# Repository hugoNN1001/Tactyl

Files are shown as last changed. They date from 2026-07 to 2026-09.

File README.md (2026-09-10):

# Tactyl

Tactyl is a gesture-based typing interface that lets you type anywhere without a keyboard. It converts finger taps into digital characters, avoiding the fixed workspace and repetitive wrist/hand positioning that conventional keyboards require.

## Photos
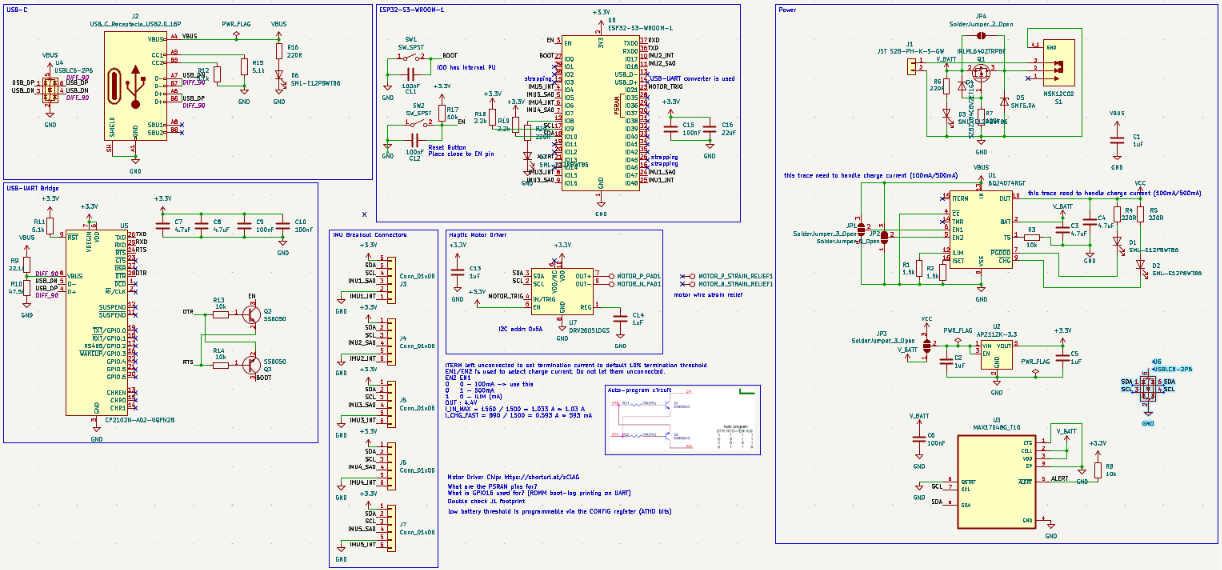
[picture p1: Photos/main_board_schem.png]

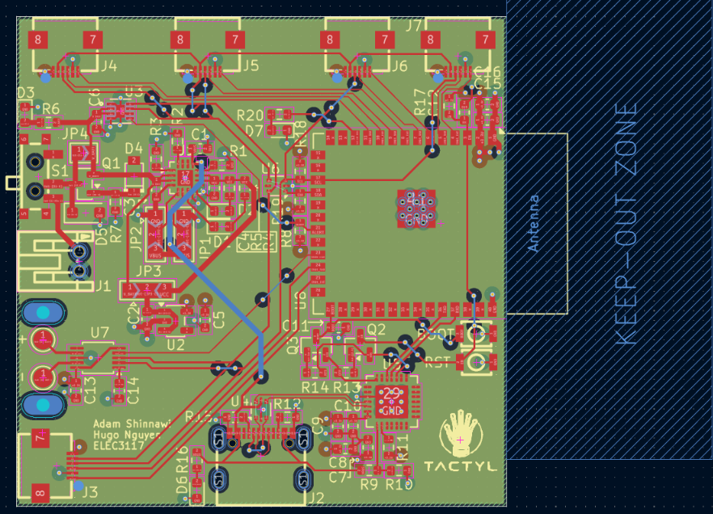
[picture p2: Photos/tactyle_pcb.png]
 
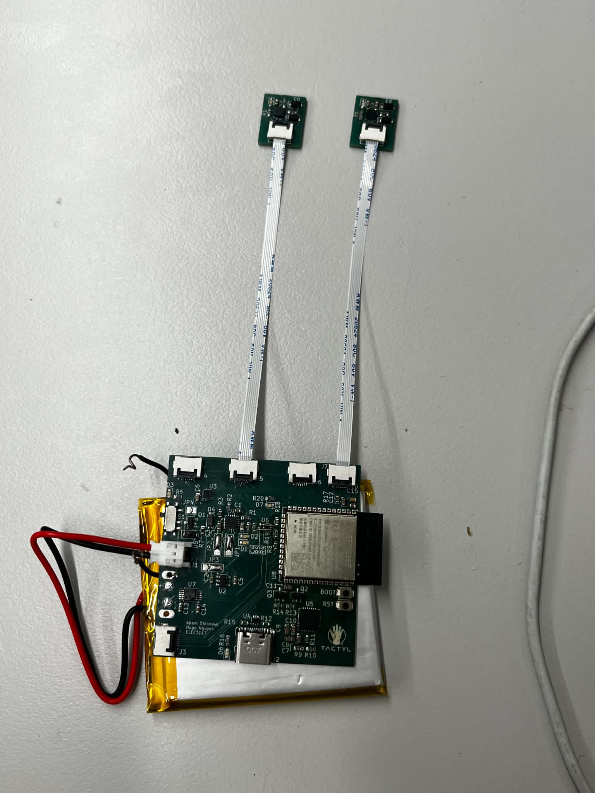
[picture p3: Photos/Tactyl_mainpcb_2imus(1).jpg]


## How It Works

Tactyl uses a **five-bit chorded input** scheme: each of the five fingers acts as one bit. Tapping different finger combinations produces unique 5-bit codes, which are mapped in software to characters and commands. This gives 32 possible combinations enough to cover the full alphabet.

Finger movement is tracked by five IMUs (one per finger) embedded in the glove, allowing the system to distinguish intentional taps from general hand motion. Sensor data is processed by an ESP32-based embedded controller and transmitted wirelessly to a host computer. A haptic feedback system provides confirmation of typed characters and connection status.

## System Architecture

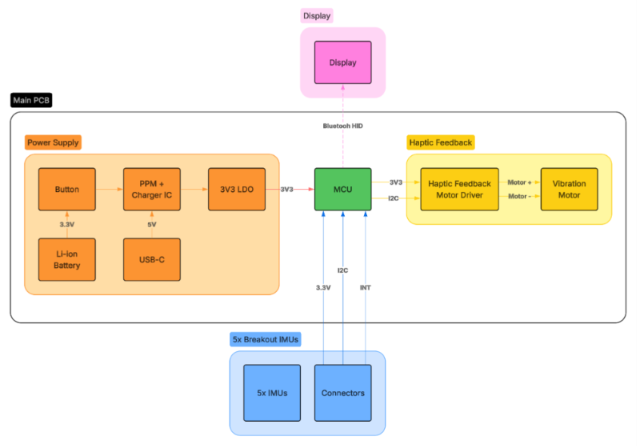
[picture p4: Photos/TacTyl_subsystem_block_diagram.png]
Tactyl subsystem block diagram


**Sensing layer.** Five **IMUs**, one per finger, each measuring acceleration to detect individual finger taps independently. Since they all share the same I²C address, a **TCA9548A I²C multiplexer** separates them into independent channels to faciliate communication.

**Power.** A **BQ24074 linear charge management IC** handles Li-ion battery charging while supporting system load via its **power-path output**. Charge current (300mA/500 mA) is selectable via solder jumpers. **Reverse polarity protection** is implemented with a P-FET with a **G-S protection diode**. The 3.3 V rail is generated by a **AP2112 LDO**. A **MAX17048 fuel gauge** monitors voltage/SOC over I²C and asserts an ALERT interrupt for **low-battery detection**, feeding the firmware's haptic alert logic. Main power traces were sized appropriate to handle the expected load. 

**Programming.** A **CP2102 USB-UART bridge** converts USB differential signals to UART to program the ESP32. Differential traces are kept short and **sized to 90Ω impedance**. ESD protection diodes are placed as close to the USB-C connector as possible.

**Processing.** An **ESP32-S3 microcontroller** processes sensor inputs, runs tap detection, maintains the five-bit finger state register, performs chord recognition, and manages communication with the host device. Each completed chord is looked up in a table and converted into the corresponding character. An **auto-program circuit** is also implemented with a pair to MOSFETs to automatically trigger BOOT & RST when programming.

**Wireless communication.** The interpreted character is transmitted over **Bluetooth Low Energy (BLE)** from the ESP32-S3 to the host device. The antenna keep-out section is kept clear of any copper.

**Haptic feedback.** A vibration motor, driven by a **DRV2605L haptic driver**, gives the user tactile confirmation of events such as BLE connection/disconnection state and low power. An **ERM coin vibration motor** is mounted through **strain-relief holes** on the main PCB. For the next version, a better decoupling capacitor should be added to prevent the ESP from resetting during strong motor vibrations.

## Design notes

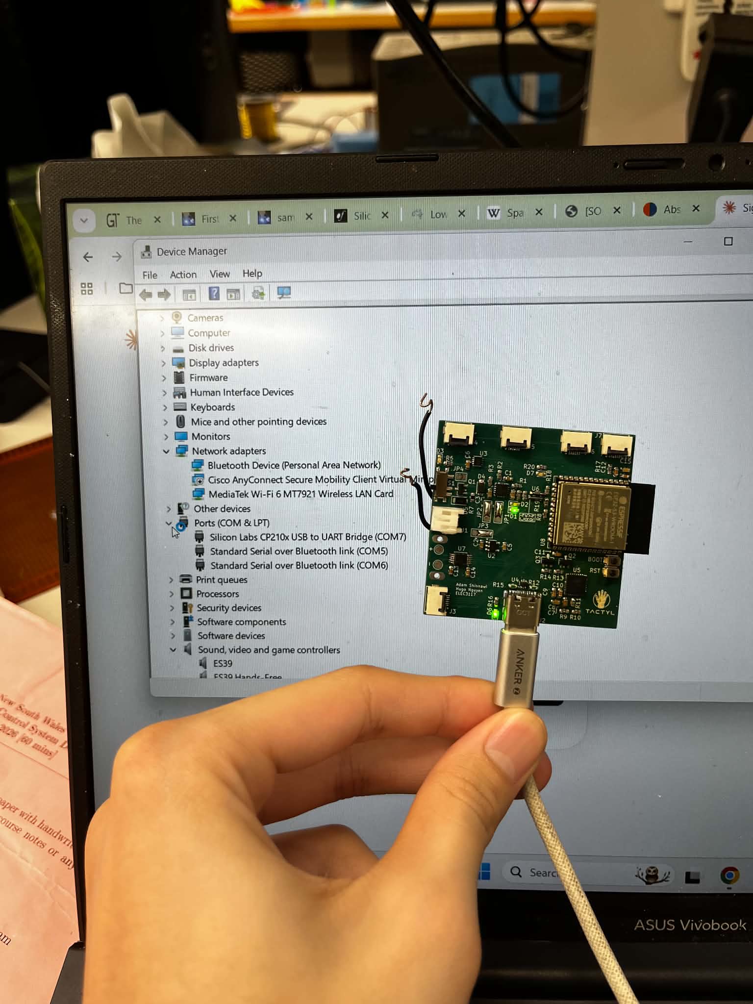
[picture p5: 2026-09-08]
Photos/Tactyl_mainpcb_2imus.jpg

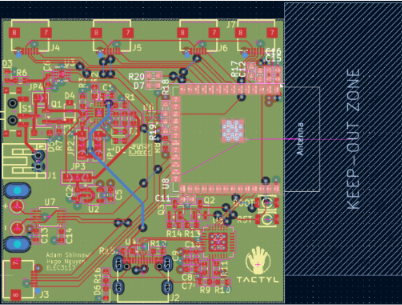
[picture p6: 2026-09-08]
Photos/main_board_pcb.png

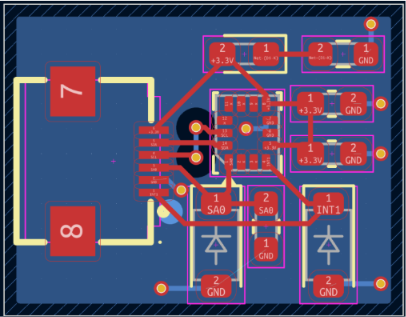
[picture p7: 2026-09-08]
Photos/IMU_breakout_board_pcb.png

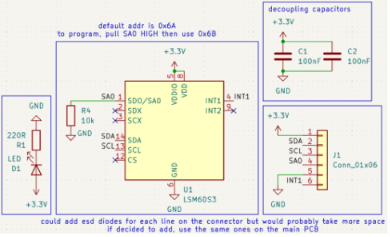
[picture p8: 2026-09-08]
Photos/IMU_breakout_board_schem.png

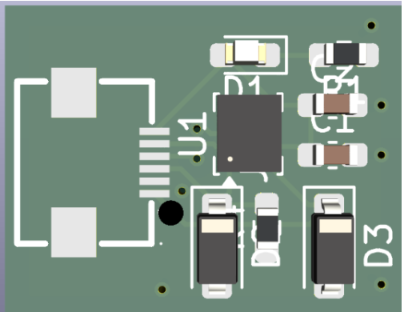
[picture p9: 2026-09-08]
Photos/IMU_breakout_board_3d.png

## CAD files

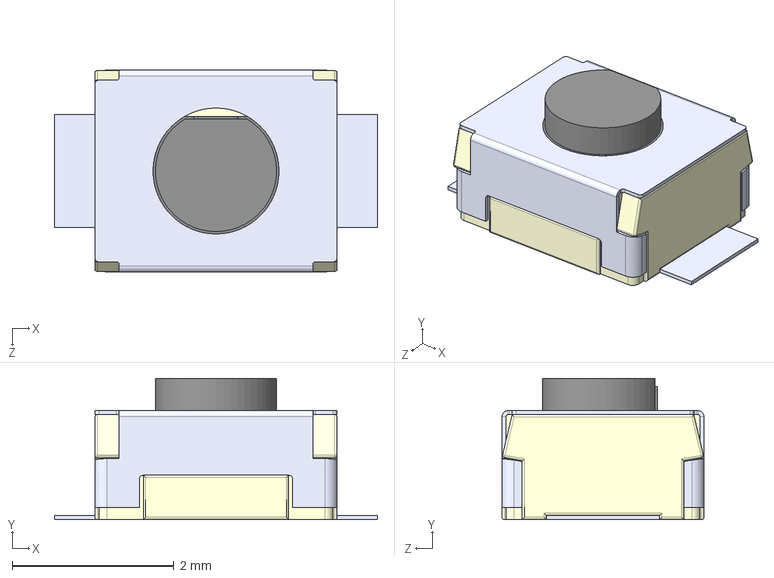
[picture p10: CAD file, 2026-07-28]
TapType_MainPCB/B3U-1000P/B3U-1000P.step
4.00 x 1.75 x 2.50 mm

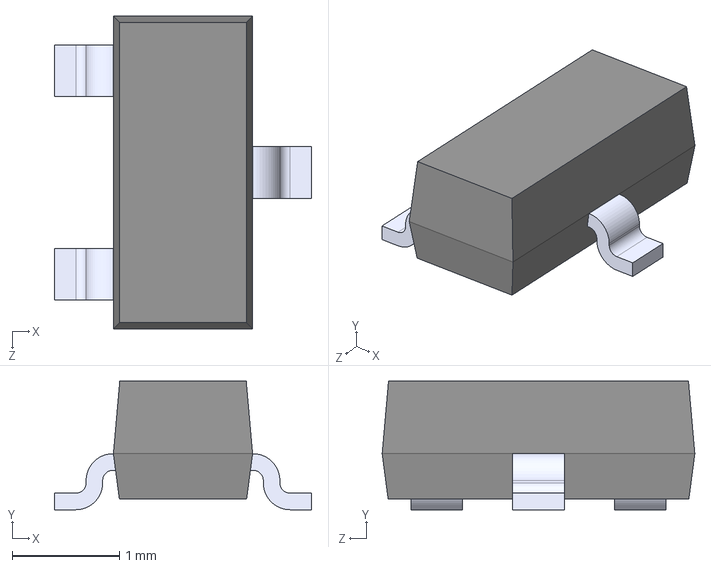
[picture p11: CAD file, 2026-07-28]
TapType_MainPCB/BZX84C6V2L/BZX84C6V2L.step
2.40 x 1.20 x 2.92 mm

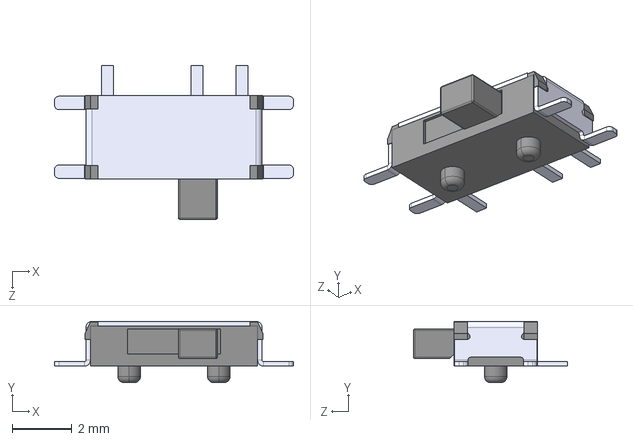
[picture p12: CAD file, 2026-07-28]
TapType_MainPCB/MSK12C02/MSK12C02.step
8.00 x 2.05 x 5.15 mm

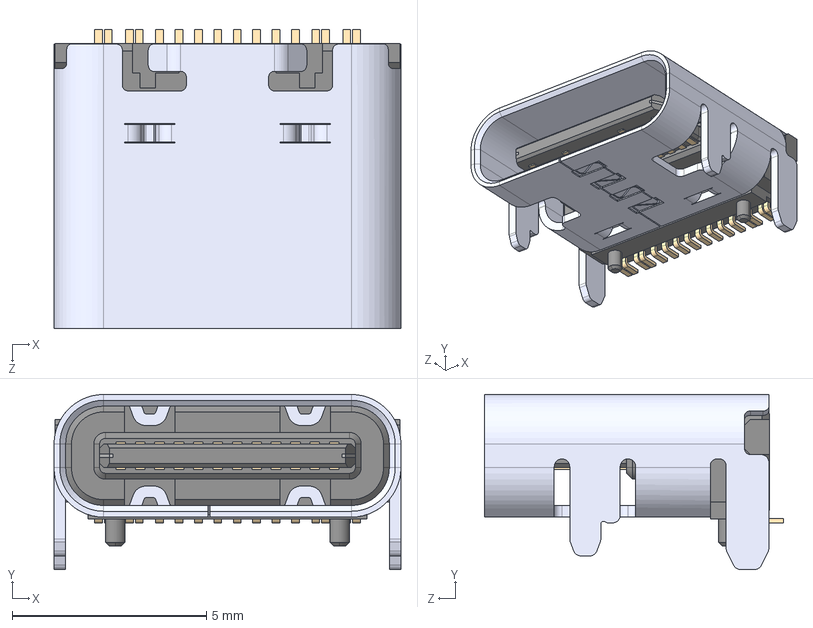
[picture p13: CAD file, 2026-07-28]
TapType_MainPCB/USB4105-GF-A-120/USB4105-GF-A-120.step
8.94 x 4.51 x 7.71 mm

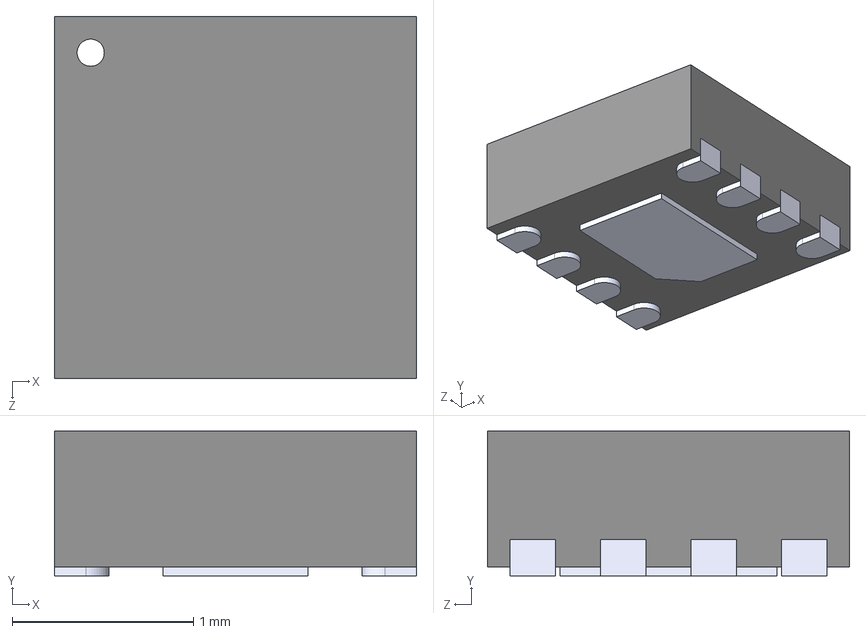
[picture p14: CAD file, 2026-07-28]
TapType_MainPCB/MAX17048G_T10/MAX17048G_T10.step
2.00 x 0.8 x 2.00 mm

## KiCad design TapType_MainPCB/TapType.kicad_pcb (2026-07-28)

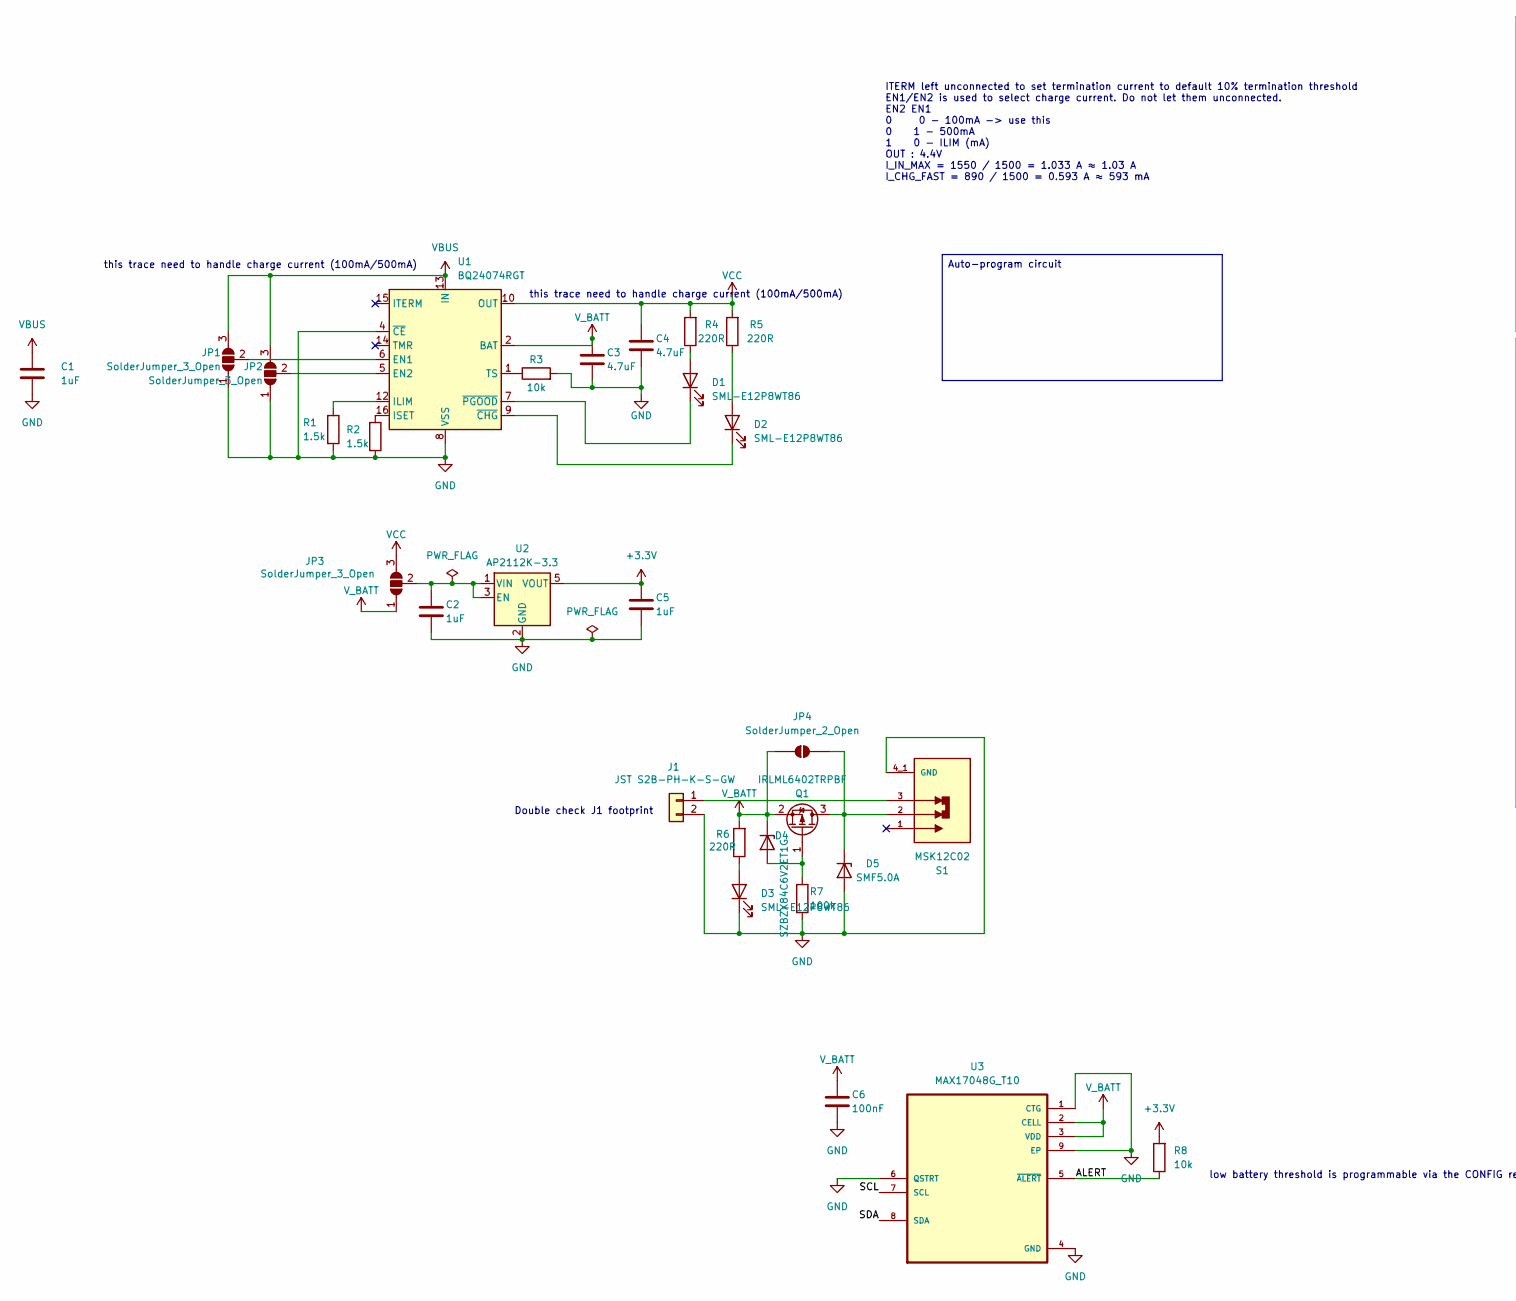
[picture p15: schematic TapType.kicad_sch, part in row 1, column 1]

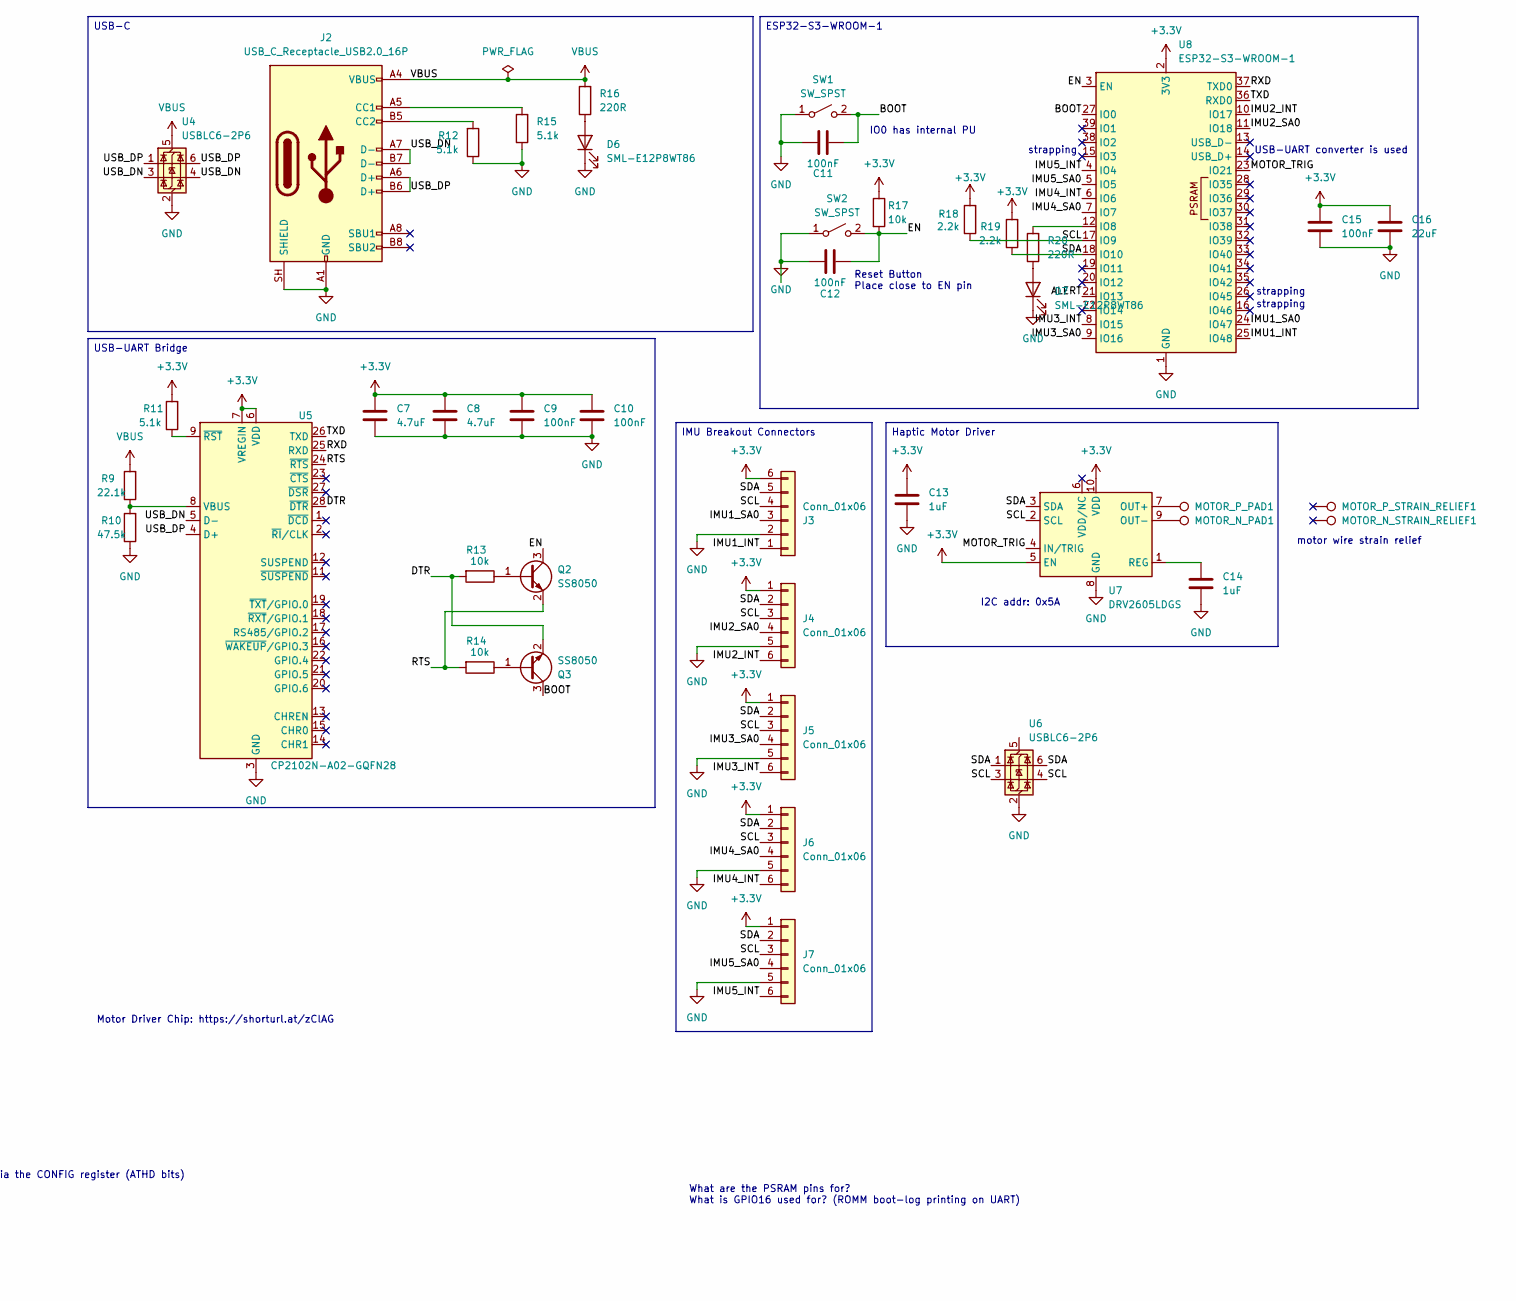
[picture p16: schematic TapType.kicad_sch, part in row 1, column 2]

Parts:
C1, C2, C5, C13, C14: 1uF; C_0603_1608Metric
C3, C4, C7, C8: 4.7uF; C_0603_1608Metric
C6, C9, C10, C11, C12, C15: 100nF; C_0603_1608Metric
C16: 22uF; C_0603_1608Metric
D1, D2, D3, D6, D7: SML-E12P8WT86; D_0603_1608Metric
D4: SZBZX84C6V2ET1G; SOD-123_L2.7-W1.6-LS3.7-RD
D5: SMF5.0A; D_SOD-123F
J1: JST S2B-PH-K-S-GW; CONN-TH_S2B-PH-K-S-GW
J2: USB_C_Receptacle_USB2.0_16P; TYPE-C-SMD_SBC-160S1A-20-S412
J3, J4, J5, J6, J7: Conn_01x06; FPC-SMD_6P-P0.50_FPC-05FB-6PH20
JP1, JP2, JP3: SolderJumper_3_Open; SolderJumper-3_P2.0mm_Open_TrianglePad1.0x1.5mm
JP4: SolderJumper_2_Open; SolderJumper-2_P1.3mm_Open_TrianglePad1.0x1.5mm
MOTOR_N_PAD1: TestPoint; TestPoint_Pad_D2.0mm
MOTOR_N_STRAIN_RELIEF1: TestPoint; strain relief
MOTOR_P_PAD1: TestPoint; TestPoint_Pad_D2.0mm
MOTOR_P_STRAIN_RELIEF1: TestPoint; strain relief
Q1: IRLML6402TRPBF; SOT-23
Q2, Q3: SS8050; SOT-23
R1, R2: 1.5k; R_0603_1608Metric
R3, R8, R13, R14, R17: 10k; R_0603_1608Metric
R4, R5, R6, R16, R20: 220R; R_0603_1608Metric
R7: 100k; R_0603_1608Metric
R9: 22.1k; R_0603_1608Metric
R10: 47.5k; R_0603_1608Metric
R11, R12, R15: 5.1k; R_0603_1608Metric
R18, R19: 2.2k; R_0603_1608Metric
S1: MSK12C02; SW-SMD_G-SWITCH_MK-12C02-G015; PARTREV A/0
SW1, SW2: SW_SPST; KEY-SMD_B3U-1000PM
U1: BQ24074RGT; VQFN-16-1EP_3x3mm_P0.5mm_EP1.6x1.6mm
U2: AP2112K-3.3; SOT-23-5
U3: MAX17048G_T10; SON50P200X200X80-9N
U4, U6: USBLC6-2P6; SOT-666
U5: CP2102N-A02-GQFN28; QFN-28-1EP_5x5mm_P0.5mm_EP3.35x3.35mm
U7: DRV2605LDGS; TSSOP-10_3x3mm_P0.5mm
U8: ESP32-S3-WROOM-1

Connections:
+3.3V: C5.1, C7.1, C8.1, C9.1, C10.1, C13.1, C15.1, C16.1, J3.6, J4.1, J5.1, J6.1, J7.1, R8.2, R11.2, R17.1, R18.2, R19.2, U2.5 (VOUT), U5.6 (VDD), U5.7 (VREGIN), U7.5 (EN), U7.10 (VDD), U8.2 (3V3)
/ALERT: R8.1, U3.5 (~ALERT), U8.21 (IO13)
/BOOT: C11.2, Q3.3 (C), SW1.2 (B), U8.27 (IO0); also elsewhere on the board
/DTR: Q3.2 (E), R13.2, U5.28 (~DTR)
/EN: C12.1, Q2.3 (C), R17.2, SW2.2 (B), U8.3 (EN); also elsewhere on the board
/IMU1_INT: J3.1, U8.25 (IO48)
/IMU1_SA0: J3.3, U8.24 (IO47)
/IMU2_INT: J4.6, U8.10 (IO17)
/IMU2_SA0: J4.4, U8.11 (IO18)
/IMU3_INT: J5.6, U8.8 (IO15)
/IMU3_SA0: J5.4, U8.9 (IO16)
/IMU4_INT: J6.6, U8.6 (IO6)
/IMU4_SA0: J6.4, U8.7 (IO7)
/IMU5_INT: J7.6, U8.4 (IO4)
/IMU5_SA0: J7.4, U8.5 (IO5)
/MOTOR_TRIG: U7.4 (IN/TRIG), U8.23 (IO21)
/RTS: Q2.2 (E), R14.2, U5.24 (~RTS)
/RXD: U5.25 (RXD), U8.37 (TXD0)
/SCL: J3.4, J4.3, J5.3, J6.3, J7.3, R18.1, U3.7 (SCL), U6.3 (I/O2), U6.4 (I/O2), U7.2 (SCL), U8.17 (IO9)
/SDA: J3.5, J4.2, J5.2, J6.2, J7.2, R19.1, U3.8 (SDA), U6.1 (I/O1), U6.6 (I/O1), U7.3 (SDA), U8.18 (IO10)
/TXD: U5.26 (TXD), U8.36 (RXD0)
/USB_DN: J2.A7 (D-), J2.B7 (D-), U4.3 (I/O2), U4.4 (I/O2), U5.5 (D-)
/USB_DP: J2.A6 (D+), J2.B6 (D+), U4.1 (I/O1), U4.6 (I/O1), U5.4 (D+)
GND: C1.2, C2.2, C3.2, C4.2, C5.2, C6.2, C7.2, C8.2, C9.2, C10.2, C11.1, C12.2, C13.2, C14.2, C15.2, C16.2, D3.1 (K), D5.2 (A), D6.1 (K), D7.1 (K), J1.2, J2.A1 (GND), J2.A12 (GND), J2.B1 (GND), J2.B12 (GND), J2.SH (SHIELD), J3.2, J4.5, J5.5, J6.5, J7.5, JP1.1 (A), JP2.1 (A), R1.2, R2.2, R3.2, R7.2, R10.1, R12.1, R15.1, S1.4_1 (GND), S1.4_2 (GND), S1.4_3 (GND), S1.4_4 (GND), SW1.1 (A), SW2.1 (A), U1.4 (~CE), U1.8 (VSS), U1.17 (VSS), U2.2 (GND), U3.1 (CTG), U3.4 (GND), U3.6 (QSTRT), U3.9 (EP), U4.2 (GND), U5.3 (GND), U5.29 (GND), U6.2 (GND), U7.8 (GND), U8.1 (GND), U8.40 (GND), U8.41 (GND); also elsewhere on the board
unnamed: D1.2 (A), R4.1
unnamed: D1.1 (K), U1.7 (~PGOOD)
unnamed: D2.2 (A), R5.1
unnamed: D2.1 (K), U1.9 (~CHG)
unnamed: D3.2 (A), R6.1
unnamed: D4.1 (A_1), Q1.1 (G), R7.1
unnamed: D5.1 (K), JP4.1 (A), Q1.3 (D), S1.2
unnamed: D6.2 (A), R16.1
unnamed: D7.2 (A), R20.1
unnamed: J1.1, S1.3
unnamed: J2.A5 (CC1), R15.2
unnamed: J2.B5 (CC2), R12.2
unnamed: JP1.2 (C), U1.6 (EN1)
unnamed: JP2.2 (C), U1.5 (EN2)
unnamed: C2.1, JP3.2 (C), U2.1 (VIN), U2.3 (EN)
unnamed: Q2.1 (B), R13.1
unnamed: Q3.1 (B), R14.1
unnamed: R1.1, U1.12 (ILIM)
unnamed: R2.1, U1.16 (ISET)
unnamed: R3.1, U1.1 (TS)
unnamed: R9.1, R10.2, U5.8 (VBUS)
unnamed: R11.1, U5.9 (~RST)
unnamed 46: MOTOR_P_PAD1.1, U7.7 (OUT+); also elsewhere on the board
unnamed 47: MOTOR_N_PAD1.1, U7.9 (OUT-); also elsewhere on the board
unnamed: C14.1, U7.1 (REG)
unnamed: R20.2, U8.12 (IO8)
VBUS: C1.1, J2.A4 (VBUS), J2.A9 (VBUS), J2.B4 (VBUS), J2.B9 (VBUS), JP1.3 (B), JP2.3 (B), R9.2, R16.2, U1.13 (IN), U4.5 (VBUS)
VCC: C4.1, JP3.3 (B), R4.2, R5.2, U1.10 (OUT), U1.11 (OUT)
V_BATT: C3.1, C6.1, D4.3 (K), JP3.1 (A), JP4.2 (B), Q1.2 (S), R6.2, U1.2 (BAT), U1.3 (BAT), U3.2 (CELL), U3.3 (VDD)

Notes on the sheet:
motor wire strain relief
this trace need to handle charge current (100mA/500mA)
low battery threshold is programmable via the CONFIG register (ATHD bits)
USB-UART converter is used
strapping
ITERM left unconnected to set termination current to default 10% termination threshold EN1/EN2 is used to select charge current. Do not let them unconnected. EN2 EN1 0 0 - 100mA -> use this 0 1 - 500mA 1 0 - ILIM (mA) OUT : 4.4V I_IN_MAX = 1550 / 1500 = 1.033 A ≈ 1.03 A I_CHG_FAST = 890 / 1500 = 0.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
Double check J1 footprint
What are the PSRAM pins for? What is GPIO16 used for? (ROMM boot-log printing on UART)
I2C addr: 0x5A
IO0 has internal PU
Motor Driver Chip: https://shorturl.at/zClAG
Reset Button Place close to EN pin
USB-UART Bridge
Haptic Motor Driver
ESP32-S3-WROOM-1
IMU Breakout Connectors
Auto-program circuit
USB-C

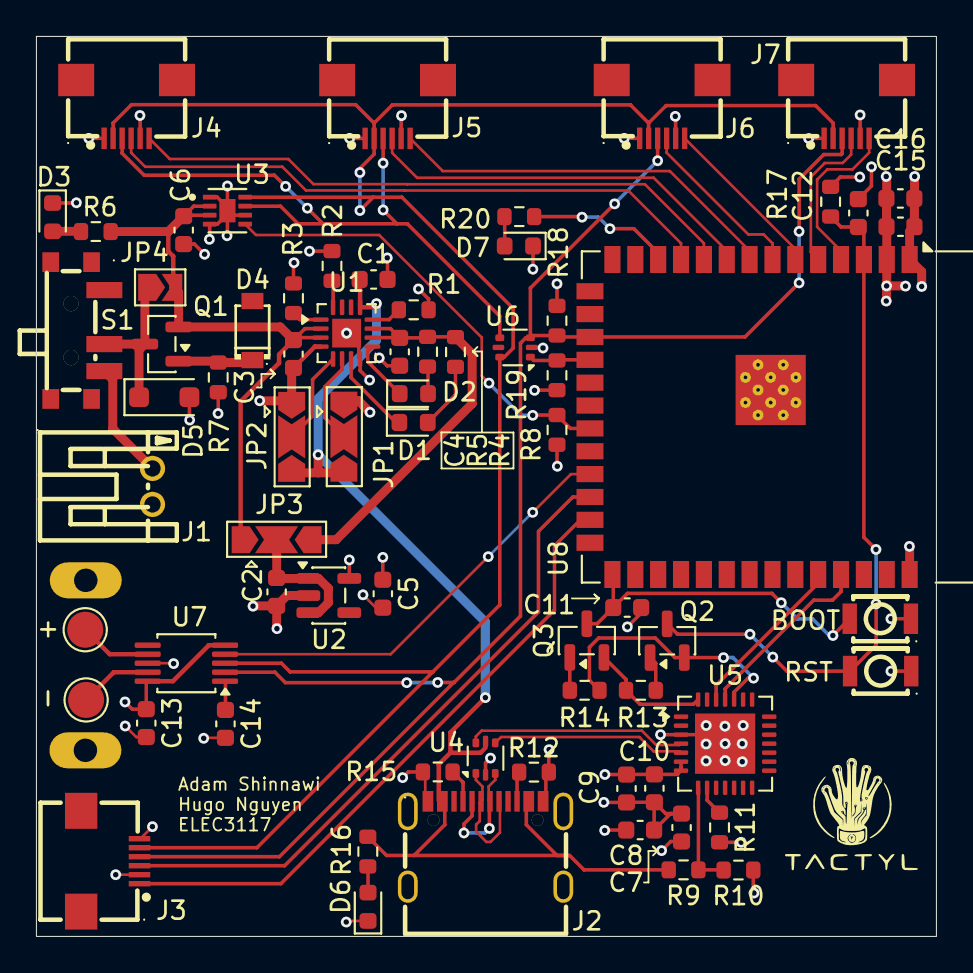
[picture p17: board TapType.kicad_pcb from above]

Board: 4 copper layers, 50.0 x 50.0 mm, 72 parts (0 on the bottom side), 53 nets.

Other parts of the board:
+: TestPoint; TestPoint_Pad_D2.0mm
-: TestPoint; TestPoint_Pad_D2.0mm
BOOT: SW_SPST; KEY-SMD_B3U-1000PM
RST: SW_SPST; KEY-SMD_B3U-1000PM

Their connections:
/BOOT: BOOT.2 (B); also elsewhere on the board
/EN: RST.2 (B); also elsewhere on the board
GND: BOOT.1 (A), RST.1 (A); also elsewhere on the board
unnamed 46: +.1 (1_1); also elsewhere on the board
unnamed 47: -.1 (1_1); also elsewhere on the board

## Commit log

2026-07-28 Finished KICAD files + Photos
    [B3U-1000P.step, BZX84C6V2L.step, MAX17048G_T10.step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]
2026-09-08 Add additional photos of final PCB
    Add additional photos of final PCB
2026-09-08 Add schematics and pcb photos
